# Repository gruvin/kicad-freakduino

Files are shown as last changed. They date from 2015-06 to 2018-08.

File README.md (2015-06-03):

# kicad-freakduino
## KiCADifying the Freakduino

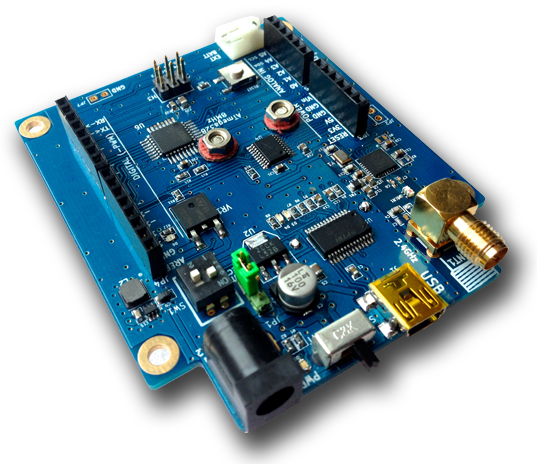
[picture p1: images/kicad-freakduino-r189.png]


I have longed for years to be able to make my own 2.4GHz, digital wireless radios.  Then I discovered and purchased a 
couple of <a href='http://www.freaklabsstore.com/index.php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'>FreakLabs "Freakduino v2.1a" boards</a>, 
as a means to learn more about low level, digital 2.4GHz RF communications. With my desire for learning, 
combined with my preference for open source EDA tools, this project was born.

<blockquote><i>Image right: Latest (final?) KiCAD-Freakduino prototype, version 1.2, revision r189</i></blockquote>

<blockquote><i>Building the three prototypes to get to this stage cost me enough to buy about ten original Freakduinos. 
Even to build one of my final version 1.2 boards, by hand and using retail priced parts, it costs significantly more 
than an original Freakduino. So if you just want to get up and running painlessly with a working board, I recommend 
you  simply <a href='http://www.freaklabsstore.com/index.php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'>buy the real thing</a>.</i></blockquote>

These Arduino compatible boards use an Atmel radio chip, intended for Zigbee standard communications. Akiba (of Freaklabs) 
wrote, "Chibi" (Japanese for "Midget") -- a light-weight communications stack, which works very well and makes 
understanding how things fit together in these systems very much simpler than a full ZigBee stack. Certainly, 
Chibi more than suffices for anything I can imagine needing for my own projects. The Arduino targeted version 
has its own project site named, <a href='http://www.freaklabs.org/index.php/chibiArduino.html'>chibiArduino</a>.

Eventually, I want to make my own boards, based on what I've learned here -- not Arduino boards, just MCU+RF 
chip and thus much smaller. In the meantime, since I had only theoretical experience with 2.4GHz radio 
communications, making my own version of a Freakduino board seemed like a good place to start. "Standing on 
the shoulders of giants", sort of thing. ;-)

I use only open source EDA tools (mostly KiCAD) for schematic capture and PCB layout design of my open source 
projects. This meant re-designing a schematic and board layout from scratch, based on the open materials 
published by FreakLabs, to whom we are all obviously very thankful. In the end, I also made a few minor 
changes to the design -- mostly due to different parts availability in my part of the world. But I've kept 
the overall layout very similar, so that the original Freakduino user-level documentation still applies 
-- jumper locations, switch settings, etc. For example, my version has a different 5-to-3.3 Volt  level 
shifter chip. The battery boost-regulator circuit is also different and is implemented in surface mount 
parts as a standard feature of the board.

The original Freakduino is already publicly licensed (Creative Commons Attribution-ShareAlike v3.0). But I 
wanted to let Akiba know what I was doing and to thank him personally for his work. I received his blessing 
2013-07-16 and immediately created this Google Code project. Thanks Akiba. I am sure we all really appreciate 
your efforts!

<h2>Progress as at 2013-11-07</h2>

My KiCAD design has now gone through several revisions and improvements. There are some changes to the 
components used, due to local availability as much as anything. But I've kept all the switches and jumper 
locations and functions the same as the original, such that the existing Freakduino v2.1a user documentation 
still applies.

I had revision <a href='https://code.google.com/p/kicad-freakduino/source/detail?r=101'>r101</a> PCBs 
fabricated. But there were errors found before those even arrived. Revision r116 was then fabricated 
and subsequently built. Unfortunately, that had errors as well and needed patching to get working. See 
<a href='Milestones.md'>Milestones</a> for details.

Finally, a version 1.2 revision r189 was built and seems to have come out all OK. Yay \o/

Below is a KiCAD 3D view of the present, r181 design, which is almost identical to the final 
r189 ...

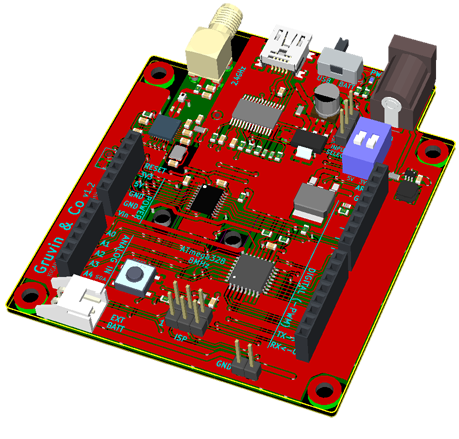
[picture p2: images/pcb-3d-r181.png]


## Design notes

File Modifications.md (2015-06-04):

# Modifications (compared to authentic Freakduino)

## DC-DC Voltage Up Converter ##

Originally, I couldn't find the TO-98 (through-hole) packaged Holtek HT7750A, at all. So, I found part of similar function, the Texas Instruments TPS61222, in it's tiny SC-70 SMD package.

Later, I found and acquired the Holtek part from a Chinese supplier. But I decided to stick with the SMD part anyway, simply because I prefer SMD to through-hole components.

## Digital Level Shifter — GTL2003 instead of FXMA108

Again, I originally could not find a supplier for the FXMA108 and again, finally found and acquired the part from China. But the GTL2003 is an easer part to handle by hand and I'd already done the routing design by then. So I'm sticking with that, too.

Note that this part's equivalent /ENABLE pin has reverse sense, to the FXMA108. The the circuit around JP2 was modified accordingly.

## FT232RL USB-to-Serial Converter

The option exists to go open hardware for this part, by changing to the ATmega16U2, with a 16MHz xtal and firmware from the Arduino archives. I think it would be a very tight squeeze to get the AT'16U2 on the board, mostly due to the need for ISP programming pads. But it does look doable, maybe.

(Incidentally, the power consumption of the ATmega16U2 at 16MHz/5V and FT232RL are both about the same. But it matters not anyway, because that circuit is only powered up when a USB cable is connected.)

## UNO `R3` Additional SDA/SCL pins (D14/15)

I briefly considered adding the extra Arduino pins, beside D13, for I2C SDA and SCL. But since these already appear on the, "analog in" pins 4 an 5, I see no point in doing so. Instead, I have simply added silk text SDA and SCL next to analog pins 4 and 5. (r79)

## Custom Routing and Lots of Learning around the RF Section

I never bothered looking for the original author's CAD files for the PCB, because I wanted to gain my own experience in routing up a board of this nature -- especially regards the 2.4GHz RF section.

RF circuitry can be like black magic. It's just not as simple as connecting two or more points together with coper and calling it a job done well. PCB track widths, lengths, spacing from each other and to ground planes and even the thickness and precise constituency of the PCB board itself, all become important at these high frequencies!

As it happened, I did make a number of newbie/amateur mistakes in just those regards, realising errors only after days of studying and reflection, having initially thought I'd got it right -- but far from it. After reading the data sheets and reviewing knowledge from over the years, I think I finally arrived at an appropriate layout.

I also took a magnifying lens to the physical Freakduino boards I had purchased, to see how Akiba had done things in the RF section. Initially, I didn't understand why some of the things were done in such a way. Moreover, I didn't even notice some details -- for days -- which in fact turned out to be quite important.

I wanted to make sure I could state confidently _why_ each and every little thing was the way it was in the Freakduino design. I didn't want to assume that it was all done right, either. Reading data sheets and refreshing my matched line theory for 2.4GHz got me there eventually -- I hope. It also appears that Akiba did a fine job, indicating that he has at least as good a handle on the subject as I have managed to cobble together, which is good to know.

In any case, the RF section is done as best I can calculate or theorise it can be, using my available skills and current knowledge. Eventually, I ended up with nearly the same layout as Akiba, for presumably the same technical reasons. Truly, that took several iterations and a lot of reading to actually arrive at. So, I really found it all to be an interesting and valuable exercise.

I do still wonder if there shouldn't ideally be an additional ferrite bead/choke, separating (RF wise) digital and analog grounds, at the digital Vcc corner of the RF chio's grounding pad. I kind of accidentally made provision for adding a ferrite, by cutting just one relatively narrow track. But didn't actually install pads for one. Perhaps I should have.  This leads me onto the next, related topic ...

What I don't know, is how to really test this thing's performance. I have a frequency counter theoretically cable of clocking a 2.4GHz signal at 8 digits resolution, to see if I'm at least on channel. (Slim chance it won't be anyhow.) But I have no idea how to go about testing tuned circuitry attenuation from transmission line impedance mismatch etc, at this ultra-high frequency (UHF). I imagine there is a test procedure published somewhere, probably involving an output power calibrated signal source with high quality 50-ohm termination, to test the receiver performance again factory specifications.  Likely the same for power output at the SMA antenna socket. Knowing spectral purity of a steady carrier and being able to test that under various digital noise conditions would be nice, too. But I simply don't have access to any equipment of that nature -- certainly not any that would work at these high frequencies.

So I'm just going to have to trust in the theory and my application thereof and hope I've got things good enough. That said, I am pretty confident, given the research and care I eventually put into the design and that I believe I understand precisely why each little detail is needed. If I'm unlucky and it turns out that I get really lousy range out of my design, then I'll be stuck for a solution, for sure. I don't like that prospect, at all.  If all goes well, I can see a number of matchbox sized wireless sensors or controllers springing up around my home -- all hand built. That should be fun!

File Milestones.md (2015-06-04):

# Project Milestones #
Most recent at the top

```

```

## Final Prototype Built and Working ##

2013-11-07:  Version 1.2 (r189) is finally built and fully operational, with no further bugs having been found. Yay \o/

See the [project README](README.md) for a photo image of the board.

```

```

## All Systems Go

2013-08-17 (r178): Finally, the first-build board is fully debugged and working 100% OK.

I've learned a whole bunch of little, practical details from this project. Quite happy with the results.

Later: (r181) I've done a dozen or so more improvements around the board, mostly to the ground planes. Gosh. I don't think I've ever spent so long, futzing around with a PCB design. With this one, I seemed to endlessly find things in need of improvement. I guess I'm nervous because I already messed up twice and it cost me. Never the less, I'm pretty happy with how things stand at (r181). So, I'll probably order the FINAL (dag-gone-it! :-P) batch of prototype proofing boards, shortly.

## <b>Revision r181 - v1.2</b>

### 3D View


### PCB Layout
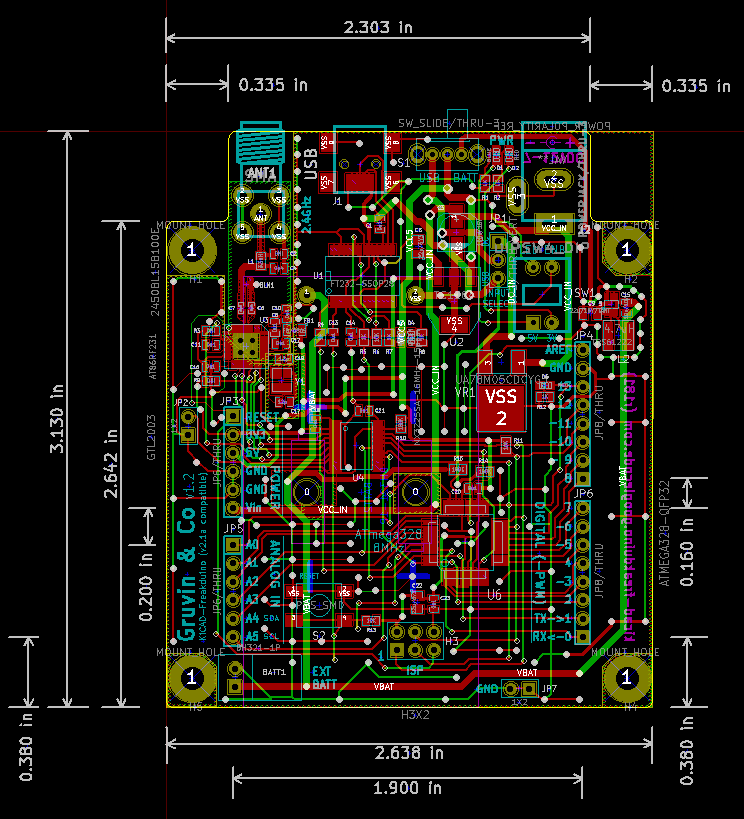
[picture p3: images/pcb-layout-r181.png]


```

```

## First Physical Build

2013-08-13: First physical test board (<a href='https://code.google.com/p/kicad-freakduino/source/detail?r=116'>r116</a>) -- patched to work around errors ...

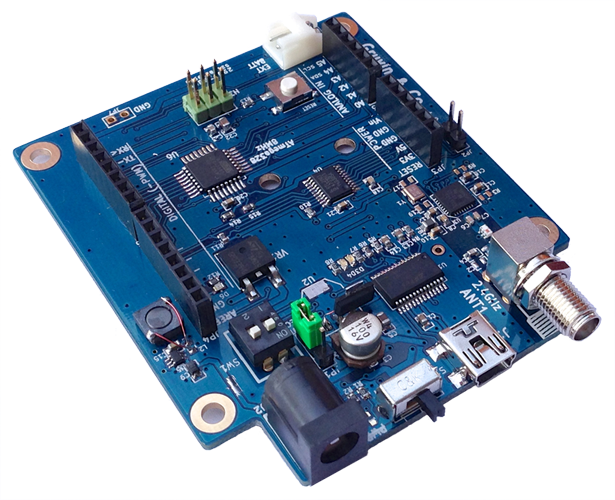
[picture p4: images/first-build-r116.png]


### Several Errors Found

<blockquote>Random Reminder: <i>I'm just an amateur home hobbyist, doing/copying this for fun and learning.</i></blockquote>

I finally got to (hand) build the first prototype (semi-clone/copy, that is) version 1.0 (<a href='https://code.google.com/p/kicad-freakduino/source/detail?r=116'>r116</a>).  Here it is ...

Alas, more errors were discovered ...

 * The slide switch pin numbering was reversed, thus reversing its function, according to silk labels and original Freakduino.
 * Due to an error in the bill of materials (BOM) spreadsheet, I had ordered the wrong 3.3V regulator, having the more common GOI pin order, instead of the prescribed IGO version.  I rigged what I had to work by standing it up and installing a wire link -- until I get the right parts in.
 * Due to another error in the BOM, I had ordered the wrong size 100uF capacitor, C3. (I had an 8mm dia. but needed a 6.3mm dia.)
 * The buck boost regulator wasn't producing the goods. The problem turned out to be that I used too small an inductor. I guess the core on the tiny 0603 part was saturating. A larger inductor (salvaged from an old hard drive and adhered to the board with shoe repair glue :-P) got things working well. Later, some NR4018 inductors were purchased and tested all good.  (That tiny TPS61222 chip can supply 500mA! Amazing.)
 * The RF chip crystal pads were mirrored. (Didn't see the word, "bottom" in the datasheet.)
 * The GTL2003 DREF/GREF pins were wired wrong, causing the chip to cook. (This time, I hadn't read the datasheet well enough, at all. <i>sigh</i>) I also realised that, since the GTL2003 is open-drain output and is connected to an SPI bus without need for external pull-ups, the ISP programming jumper JP2 is not strictly needed. But I left it in place, just in case.
 * 

As at version v1.2 (r178) the project BOM files and PCB design have been updated and corrected, according to the above. Quite a lot of general tidying was also done.

The RF section has now been tested working. But proper range tests have not yet been conducted.

<b>Frequency</b>: The original Freakduinos appear to be using an 8pF (16MHz) crystal, with 12pF capacitors. I measured the oscillator frequency at 16.9997MHz -- 500Hz lower than my 12pF crystal and caps. This represents a 31ppm difference (if you can trust my math) which seems like it should be too much. But the two radios do communicate OK. The radio chip also has internal trimmer capacitors, which can be adjusted digitally. Chibi does not appear to provide API access to this feature. I might add it.

As an experiment, I pushed the difference out to 5,000Hz (10x before) and confirmed that radio comms failed, as expected. Interesting, though.

It's hard to know exactly what frequency the 16MHz oscillator is really running at, since the test probe loads the circuit. However, I would suspect that the test probe loading reduces the frequency a little. Therefore, it appears to me more likely that Akiba's choice of an 8pF crystal is the way to go. So, I update update the BOM to an 8pF version and order some for myself. (They're not cheap here, at over $7 each!)

That said, my 8-digit counter claims to be good to 2.7GHz. So I should really use the RF chip's feature to turn on a test carrier and measure the final output. Perhaps tomorrow.

<b>Range tests not withstanding, r178 <i>might</i> be the final v1.x production-proof.</b>

Later the same day -- after some excitement initially with non-connecting antennas -- range checks and signal RSSI reports are all good. Excellent. Whew!

```

```

## PCBs Ordered for KiCAD-Freakduino v1.0 (r116)

Enough tinkering already! Time to order the first 10 prototype PCBs and get cracking.

I actually ordered boards for r101. But later found errors, which have been corrected in r116. So the r101 boards are now pretty, blue and gold tea coasters -- before they even get out of production. *sigh*

I've ordered 10x PCBs (minimum quantity) and all the parts to build two boards, with the usual bulk left-over resistors, capacitors purchased for reasons of economy and use in later projects.

<blockquote>NOTE:  Enough parts to build just two (2) of these boards has cost more than USD$200, including the PCBs. So don't bother building, unless you really want the educational experience, as I did. Instead, I recommend you simply buy genuine units from the <a href='http://freaklabsstore.com/'>freaklabsstore.com</a> at just USD$36 ea. (2013-07-23) fully built and tested.</blockquote>

My goal ultimately is not to build Arduino compatible boards, but small, bare bones boards based on what I've learned here, for use in sensor networks and for wireless remote control. I'd also like to play about with low power Bluetooth™ and Wi-Fi, as experience and understanding increases. But who knows.

### PCB Layout Overview v1.0 (r=116)

#### A 3D View v1.0 (r116)

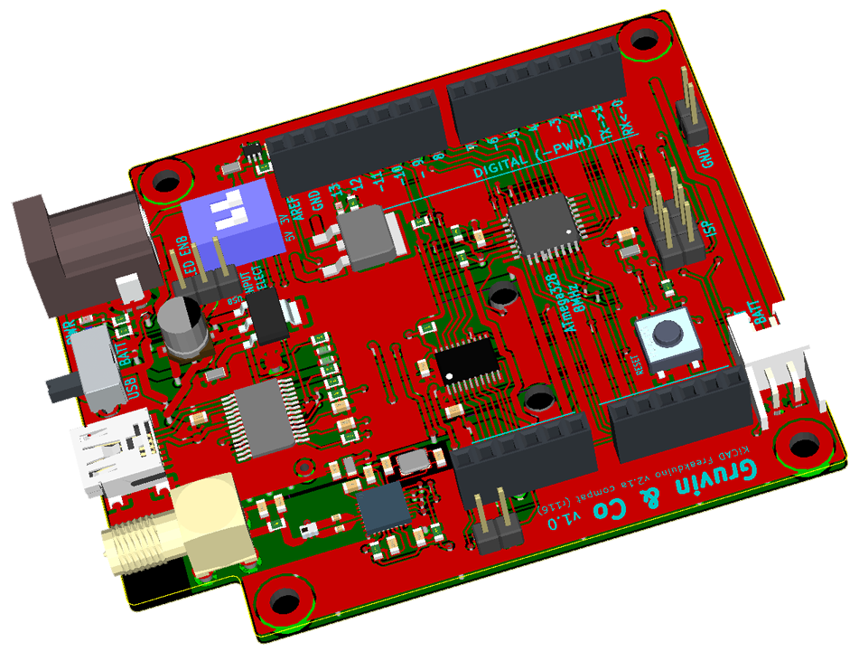
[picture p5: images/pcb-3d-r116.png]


#### CAD View v1.0 (r116)

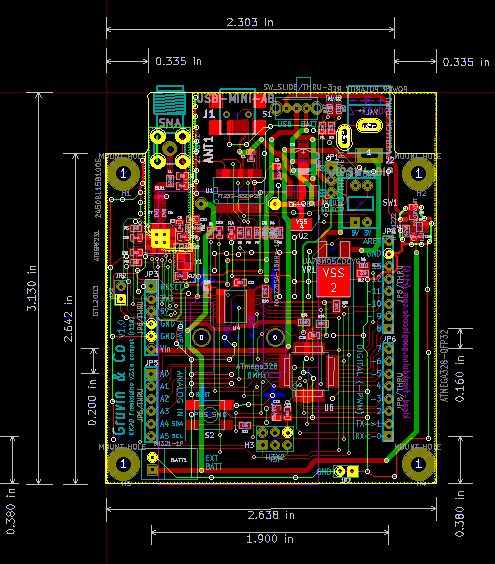
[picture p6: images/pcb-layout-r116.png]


````

```

### Notes for r116 Milestone

Some components and their related layout design work differ from the authentic Freakduino v2.1a. This was driven in the first instance from lack of availability of certain parts, at the time. A source was finally located in China and parts ordered. But I decided to stick with the more readily available versions anyway.

So, the final routing solution ended up significantly different to Akiba's original design, because it just seemed easier to route using my own brain, than trying to copy. (The different battery holder mounting hole position(s) and the two substituted chips with supporting parts mandated changes, anyway.) However, I was careful to leave the user interaction devices -- antenna and power connectors, dip switches, jumpers and LEDs -- in very similar to original locations, so that the original documentation may better apply to this design.

Some minor layout errors were found with regard to positioning of some 0u1 decoupling capacitors (C18, C20, C21 from memory) in the authentic Freakduino. Nothing serious, just some swapped positions, basically. In any case, these were "corrected" in this KiCAD rendition.

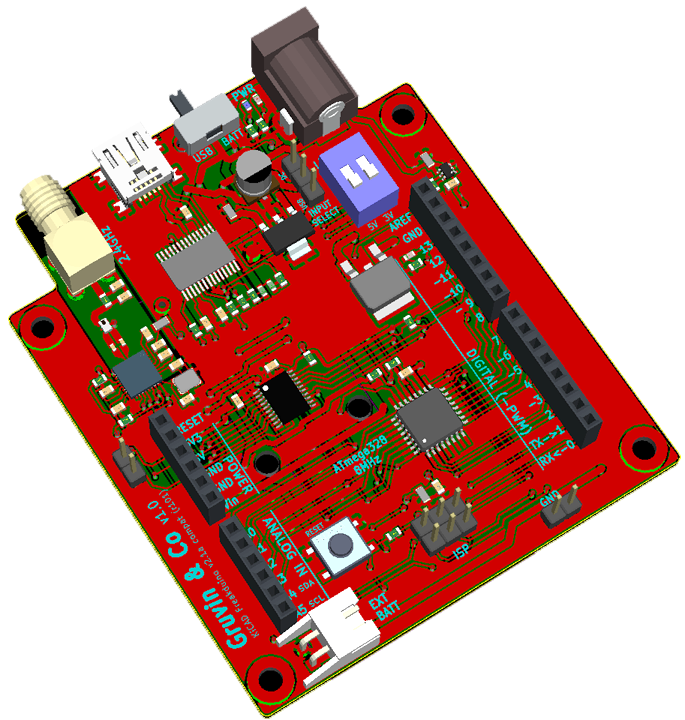
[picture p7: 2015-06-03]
images/KiCAD-Freakduino-v1.0_r101_production.png

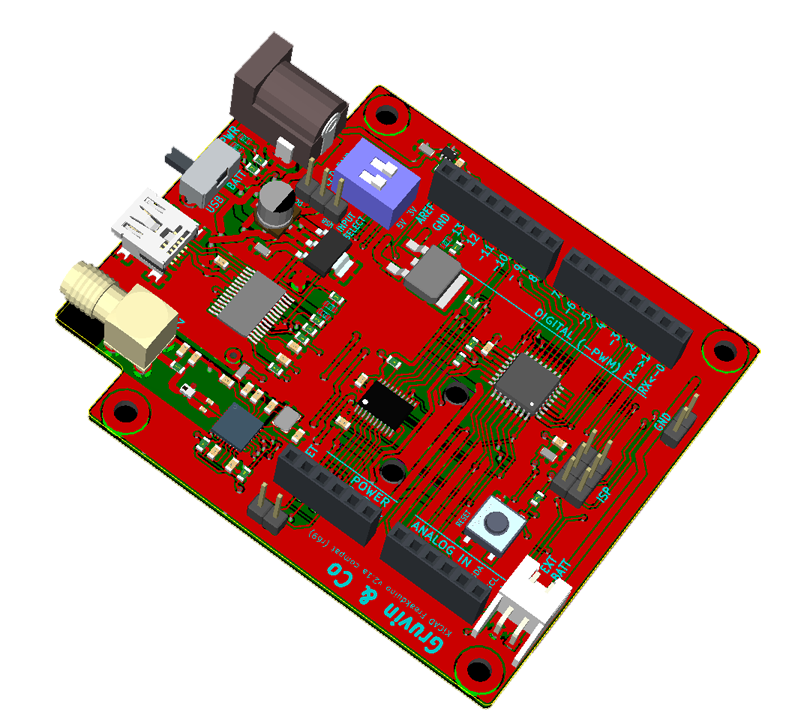
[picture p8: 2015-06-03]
images/kicad-freakduino-r90.png

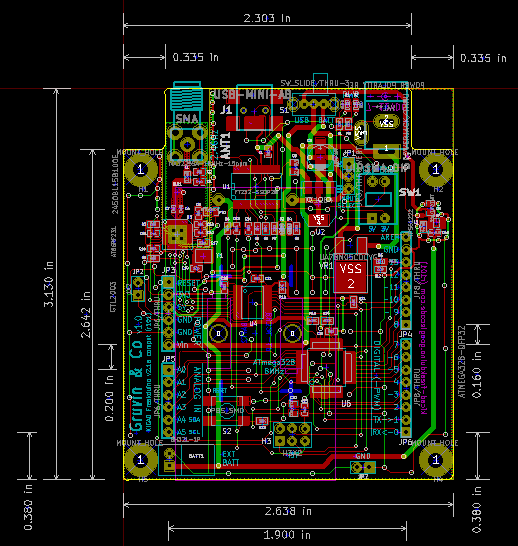
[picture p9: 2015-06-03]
images/pcb-layout-r101.png

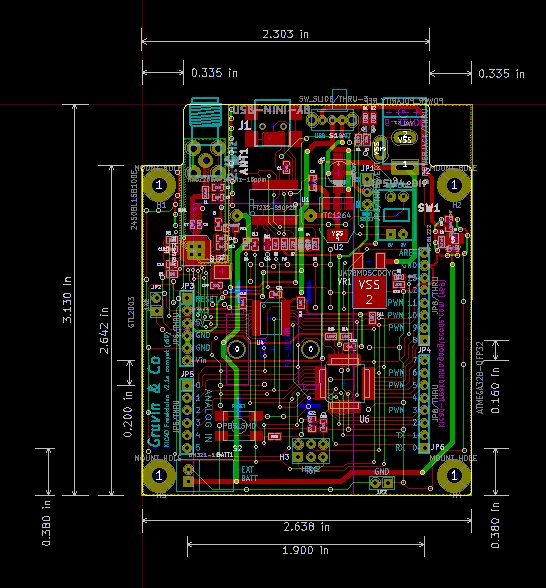
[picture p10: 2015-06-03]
images/pcb-layout-r69.png

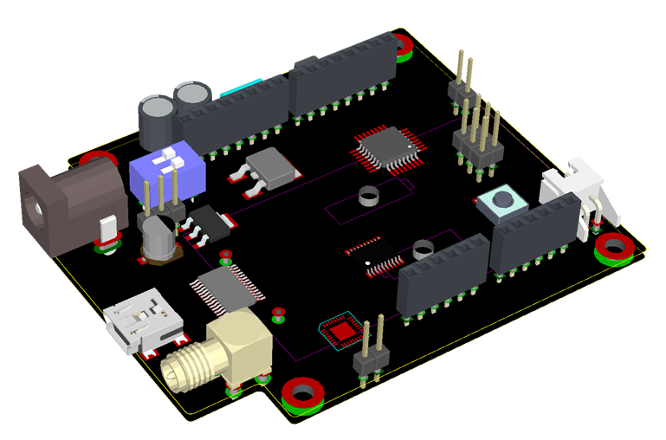
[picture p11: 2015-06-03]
images/progress-2013-07-18.png

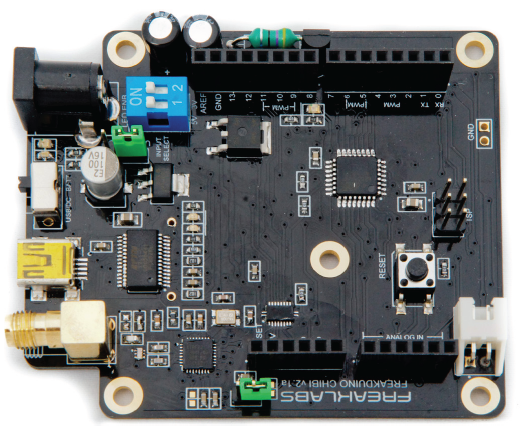
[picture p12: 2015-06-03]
images/freakduino_v2.1a.png

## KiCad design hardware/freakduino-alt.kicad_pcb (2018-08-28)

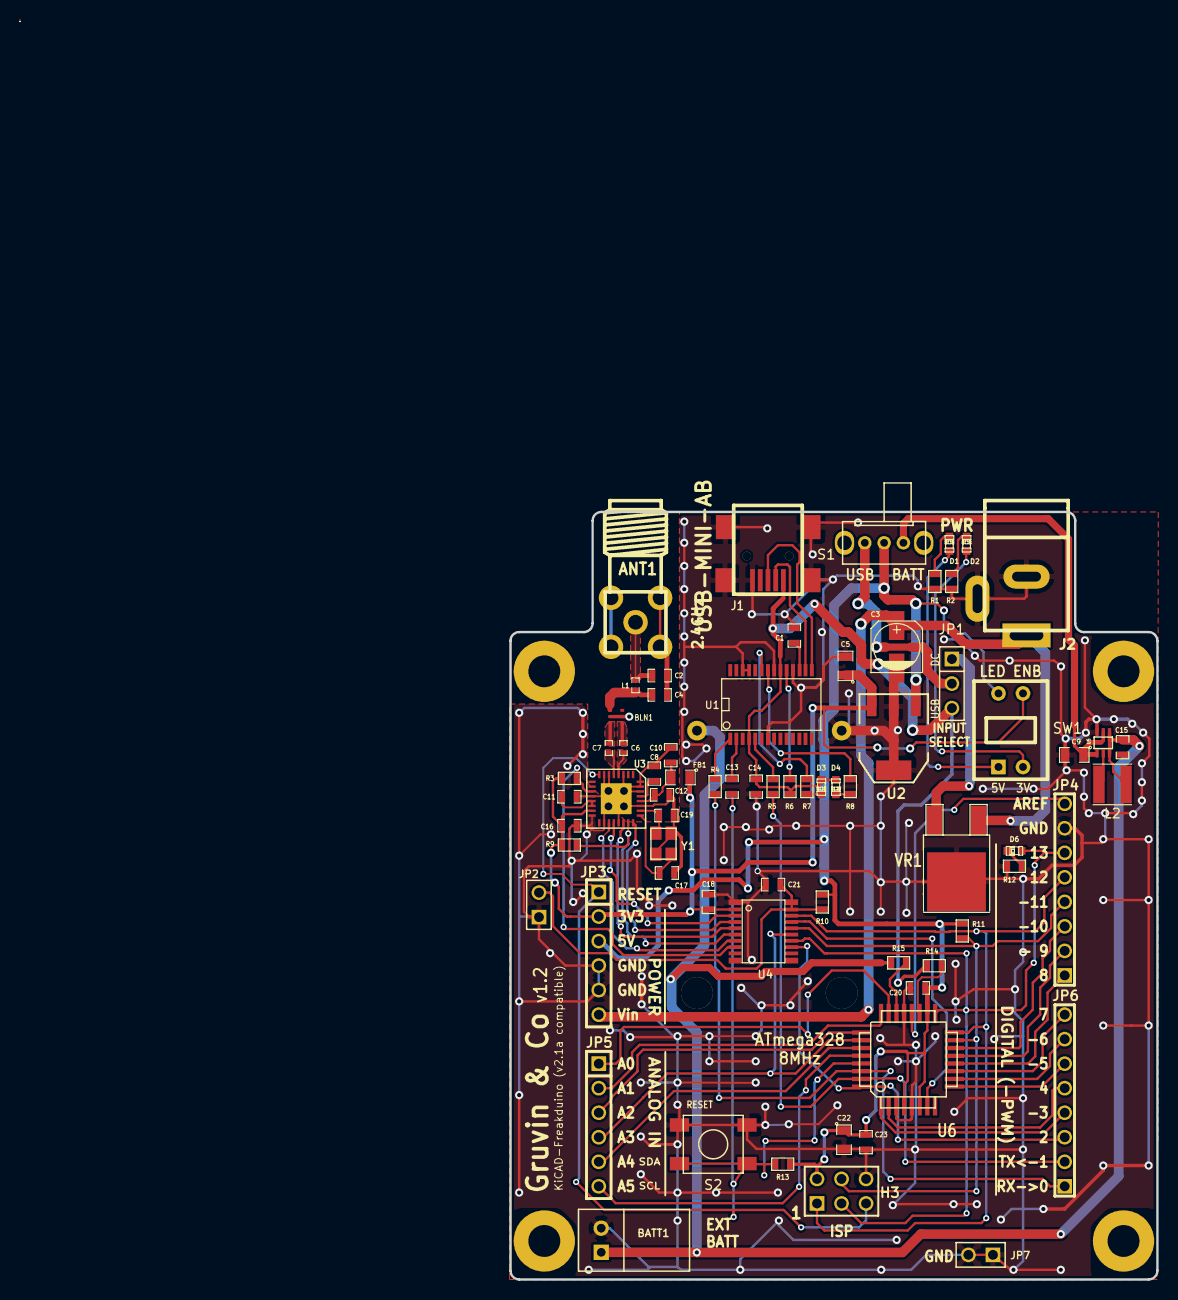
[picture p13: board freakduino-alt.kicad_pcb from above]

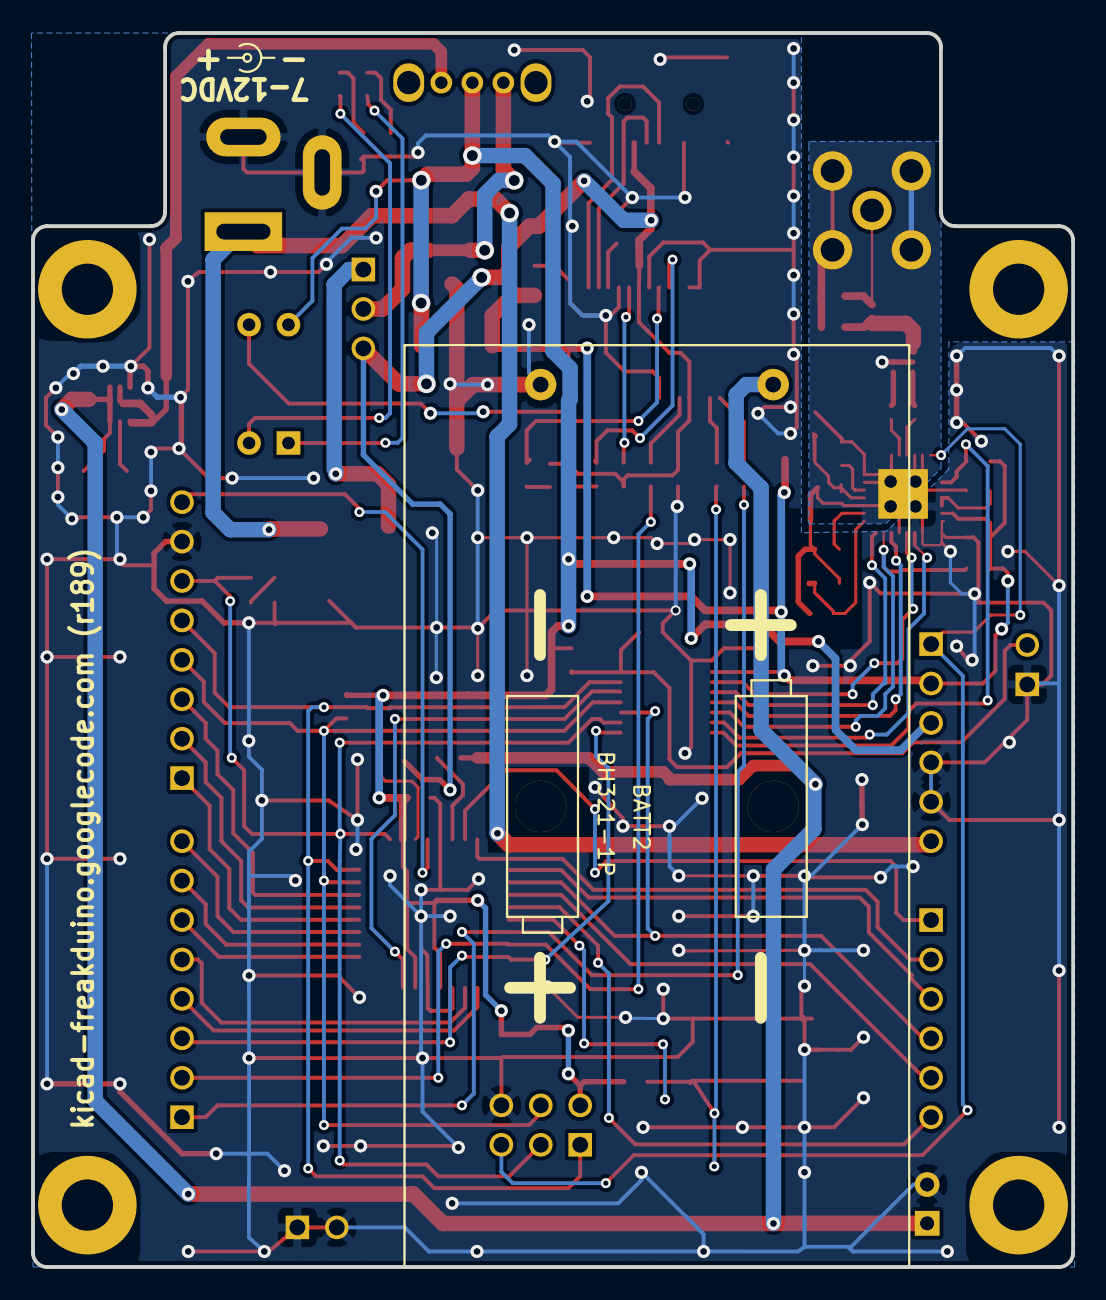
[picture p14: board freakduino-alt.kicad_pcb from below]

Board: 2 copper layers, 67.0 x 79.5 mm, 77 parts (2 on the bottom side), 69 nets.

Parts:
ANT1: SMA; SMA-GRUVIN
BATT1: BH321-1P; JST_S2B-XH-A
BATT2: BH321-1P; BATT_HOLDER_2AA
BLN1: 2450BL15B100E; BALUN_SMD_0805
C1, C10, C11, C13, C14, C16, C18, C20, C21, C23: 0u1; SM0603_Capa
C2: DNI; SM0603_Capa
C3: 100u/16V; c_elec_5x5.8
C4: 0p4; SM0603_Capa
C5: 22u/6V3; SM0805
C6, C7: 5p6; SM0402_c
C8, C12: 0u01; SM0603_Capa
C9: 22u/16V/TANT; SM0805
C15: 10u/10V; SM0603_Capa
C17, C19: 12p; SM0603_Capa
C22: 22u/6v3; SM0805
D1: BLUE; LED-0603
D2, D6: RED; LED-0603
D3, D4: GREEN; LED-0603
FB1: FB/0805; SM0805
H1, H2, H4, H5: MOUNT_HOLE; HOLE_130x250mil
H3: H3X2; pin_array_3x2
J1: USB-MINI-AB; USB-B_mini
J2: POWERJACK/THRU-3; JACK_NEB21R
JP1: JP3/THRU_VERT; PIN_ARRAY_3X1
JP2, JP7: 1X2; PIN_ARRAY_2X1
JP3, JP5: JP6/THRU; PIN_ARRAY-6X1
JP4, JP6: JP8/THRU; pin_array_8x1
L1: 3.3nH; SM0402
L2: 4.7uH; L_Taiyo-Yuden_NR-40xx
POWER_POLARITY_REF: VAL**; POWER_POLARITY_REF
R1, R2, R4, R5, R7, R8, R12: 1K; SM0603
R3, R9: DNI; SM0603
R6, R11, R13: 10K; SM0603
R10: 180K; SM0603
R14, R15: 100K; SM0603
S1: SW_SLIDE/THRU-3; SW_SPDT_SLIDE_90
S2: PBS_SMD; SWPUSH_SPST_SMD
STUB: VAL**; STUB
SW1: DIPSW4_DIP; SWDIP2
U1: FT232-SSOP28; SSOP28-GRUVIN
U2: TC1264; SOT223
U3: AT86RF231; QFN32_2x2-SINK
U4: GTL2003; SOT360-1
U5: TPS61222; SC-70-6
U6: ATMEGA328-QFP32; TQFP32
VR1: UA78M05CDCYG3; DPAK2
Y1: NX3225SA-16MHz-15ppm; crystal_C3E

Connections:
/INTERFACE/3VLED: D2.1, SW1.2
/INTERFACE/5VLED: D1.1, SW1.1
/INTERFACE/LOGIC_OE: C21.1, JP2.2, R10.1, U4.19, U4.20
/INTERFACE/VCC3_LED: D2.2, R2.2
/INTERFACE/VCC5_LED: D1.2, R1.2
/POWER/BOOST_OUT: C9.1, S1.1, U5.2, U5.4
/POWER/DC_IN: JP1.1, VR1.3
/POWER/VCC5_IN: JP1.2, S1.3
/RADIO/ANT: ANT1.1, C2.1, L1.2
/RADIO/RFN: C6.1, U3.4
/RADIO/RFN_BAL: BLN1.4, C6.2
/RADIO/RFP: C7.1, U3.5
/RADIO/RFP_BAL: BLN1.3, C7.2
/RADIO/UNBAL: BLN1.1, C4.1, L1.1
/USB/DM: J1.2, U1.16
/USB/DP: J1.3, U1.15
/USB/FTDI_RST_N: R6.2, U1.19
/USB/RXLED_N: R8.2, U1.22
/USB/TXLED_N: R7.2, U1.23
/USB/USB_3V3OUT: C1.1, U1.17
/VBATR: R15.2, U6.22
/VBUSR: R14.2, U6.19
AREF: JP4.8, U6.20
DTR_N: C13.1, U1.2
INT: U3.24, U4.4
MCU_RX: R4.2, U1.1
MCU_TX: R5.2, U1.5
MISO: U3.20, U4.3
MOSI: U3.22, U4.5
unnamed: L2.2, U5.5
unnamed: C8.1, U3.29
unnamed: C17.1, U3.25, Y1.3
unnamed: C19.1, U3.26, Y1.1
unnamed: C11.1, U3.13, U3.14
unnamed: C10.1, C12.1, FB1.2, U3.28
unnamed: D4.2, R8.1
unnamed: D3.2, R7.1
unnamed: D6.2, R12.2
PB0/ICP1: JP4.1, U6.12
PB1/OC1A: JP4.2, U6.13
PB2/~SS~/OC1B: JP4.3, U6.14
PB3/MOSI/OC2A: H3.4, JP4.4, R11.1, U4.16, U6.15
PB4/MISO: H3.1, JP4.5, U4.18, U6.16
PB5/SCLK: D6.1, H3.3, JP4.6, U4.14, U6.17
PC0/ADC0: JP5.1, U6.23
PC1/ADC1: JP5.2, U6.24
PC2/ADC2: JP5.3, U6.25
PC3/ADC3: JP5.4, U4.15, U6.26
PC4/ADC4/SDA: JP5.5, U6.27
PC5/ADC5/SCL: JP5.6, U6.28
PD0/RXD: JP6.1, R4.1, U6.30
PD1/TXD: JP6.2, R5.1, U6.31
PD2/INT0: JP6.3, U4.13, U6.32
PD3/INT1/OC2B: JP6.4, U6.1
PD4/T0: JP6.5, U6.2
PD5/T1/OC0B: JP6.6, U6.9
PD6/OC0A/AIN0: JP6.7, U6.10
PD7/AIN1: JP6.8, U6.11
RADIO_INT: U4.17, U6.7
RADIO_SEL_N: R9.2, U3.23, U4.6
RESET_N: C13.2, H3.5, JP3.1, R13.1, S2.3, S2.4, U3.8, U6.29
SCLK: U3.19, U4.7
SLP_TR: R3.2, U3.11, U4.8
VBAT: BATT1.1, BATT2.1, C15.1, L2.1, R15.1, U5.1, U5.6
VBUS: C14.1, D3.1, D4.1, J1.1, JP1.3, R6.1, R14.1, U1.4, U1.20
VCC3: C5.1, C16.1, C18.1, FB1.1, JP3.2, R3.1, R9.1, SW1.3, U2.3, U3.15, U4.2
VCC5: C20.1, C22.1, C23.1, H3.2, JP3.3, R10.2, R11.2, R13.2, S1.2, SW1.4, U2.1, U6.4, U6.6, U6.18
VCC_IN: C3.1, J2.1, JP3.6, VR1.1
VSS: ANT1.2, ANT1.3, ANT1.4, ANT1.5, BATT1.2, BATT2.2, BLN1.2, BLN1.5, C1.2, C2.2, C3.2, C4.2, C5.2, C8.2, C9.2, C10.2, C11.2, C12.2, C14.2, C15.2, C16.2, C17.2, C18.2, C19.2, C20.2, C21.2, C22.2, C23.2, H3.6, J1.5, J1.6, J1.7, J1.8, J1.9, J2.2, J2.3, JP2.1, JP3.4, JP3.5, JP4.7, JP7.1, JP7.2, R1.1, R2.1, R12.1, S2.1, S2.2, U1.7, U1.18, U1.21, U1.25, U1.26, U2.2, U2.4, U3.3, U3.6, U3.7, U3.12, U3.16, U3.18, U3.21, U3.27, U3.30, U3.31, U3.32, U3.33, U4.1, U5.3, U6.3, U6.5, U6.21, VR1.2, Y1.2, Y1.4

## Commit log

2018-08-28 Laboriously re-worked schematic and 3D settings for KiCAD v5+
    [freakduino-alt.brd, freakduino-alt.kicad_pcb, freakduino-alt.sch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]
2018-08-28 Attempting to update sch->brd netlist component footprint a for KiCAD v5+
    [freakduino-alt.kicad_pcb, freakduino-alt.sch, interface-alt.sch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]
